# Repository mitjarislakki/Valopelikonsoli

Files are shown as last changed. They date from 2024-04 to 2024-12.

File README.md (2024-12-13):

# Valopelikonsoli

pic of console

Valopelikonsoli ("Light game console") is an Arduino-based simple 2-player game console created as part of an electrical workshop project course at Aalto University in Spring 2024. It uses a keypad matrix to handle the switches with fewer pins.

Created with PlatformIO + Arduino lib using C++ and the following libraries (defined in [platformio.ini](./platformio.ini)):
- duinowitchery/hd44780@^1.3.2
- fastled/FastLED@^3.6.0

Implemented games:
- Whack-a-mole, where the aim is to be the first to hit the yellow light which lights up on both sides, while avoiding red lights.
- Memory game, where a random pattern keeps increasing by one every time the player gets it correct (asynchronous for players)
- Speed game, where lights appear in random places and the player must press as many as possible in the time limit (asynchronous for players)

## BOM / parts

| Part | Quantity | Note |
| --- | --- | --- |
| PCF8574 I2C backpack/HD44780 16x2 LCD module |	2	| I2C-based screens, 1 per player |
| 10 K resistor |	4	| Pulldown for the columns of the matrix |
| 4.8 K resistor |	2 |	I2C pull-up |
| DT44L12-W arcade buttons with switches	| 15 | 7 buttons per player + reset |
| NeoPixel ARGB LED |	14 |	Addressable LEDs to place inside buttons |
| IN4148 Diodi |	14	| Blocking reversed current in matrix |
| Arduino UNO R3 | 1	| Microcontroller, Mini also has enough pins |
| 9V -battery	| 1	| Power source for Arduino/LEDs |
| 9V battery holder with DC5521 -jack |	1 |	Power switch and connector to Arduino |
| Dupont-connector cables	| A lot |	Male-male & male-female |

## Implementation

### Displays

displays

The original idea was to use OLED displays for both color and higher resolution, but the workshop could not find any displays of suitable size and the basic 64x128 monochrome SSD1306 would require a 64*128=8192-bit (1024 bytes) buffer, so two displays would fill the Arduino UNO's 2048 byte SRAM. In the implementation, we therefore ended up using regular 2x16 seven-segment LCD displays, but with I2C backpacks instead of SPI to save on the Arduino's pin count. The workshop's I2C-LCD displays (including the 1602 LCD module) utilize Hitachi's HD44780 LCD controller with Texas Instruments' PCF8574 I2C I/O expansion chip. We found an easy-to-use HD44780.h library for this combination, which has a separate hd44780_I2Cexp subclass for controlling the I2C backpack.

To control two I2C displays, you must ensure that the displays have different I2C addresses. In the case of LCD modules, the address change is done by soldering two marked areas on the circuit board together. In the actual connection, the SDA/SCL connections of the displays are connected in parallel, but I2C pull-up resistors are needed before the corresponding connections on the Arduino.

We attached the screens to the console frame by drilling two holes in the console on each player's side. This allowed us to attach the screens with a string.

### Frame

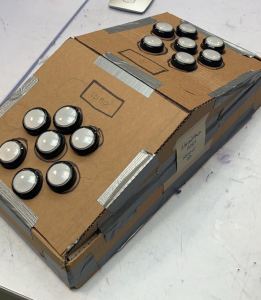
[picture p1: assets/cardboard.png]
cardboard


Cardboard prototype

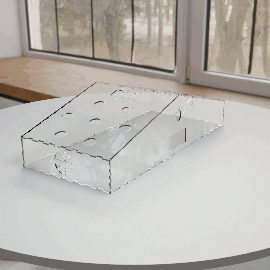
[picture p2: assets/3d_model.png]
3d model


3D model in Blender with reduced size compared to prototype. Was laser cut according to the modeled object ([SVG file](assets/laser_cutting.svg))

### Buttons

[A holder suitable for DT44L12-W buttons that can accommodate four connections for an ARGB LED](assets/LED_holder_2.stl) (STL file)

The workshop didn't have ready-made Arcade-style pushbuttons with ARGB LEDs and ready-made solutions were expensive, so we implemented them ourselves with DT44L12-W buttons. For the buttons, a four-pin holder was created for the LEDs, two of which (DIN and DOUT) work with the button connections and the power is provided by new wires coming out of the buttons.

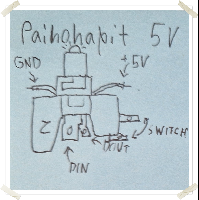
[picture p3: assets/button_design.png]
button design


The LED was attached to the printed holder so that the connections did not touch each other and the outermost connections (DIN, DOUT) were connected to the existing connections of the buttons. The new connections required two gaps between the switch and the holder, which were ground with a small file on each switch holder. The new connections were soldered with wires, which were still insulated in the printed holder with electrical tape, in order to avoid mixing of the signals of the connections.

button assembly

The functionality of the button LEDs was verified by testing both a single button and a series connection, where the DOUT of one button continues to the DIN connector of the other button. It is important to note in the project that not all ARGB LEDs are of the same type, which was reflected in the fact that some of the LEDs initialized blue when started, while some remained off. At the same time, the series connection of the LEDs did not work with every order of buttons, but a working series had to be manually tested. No reasonable explanation has been found for this, as the order did not depend on the types of LEDs. In the broken series, the LEDs started flashing randomly and did not follow the value given in the code.

### Key matrix

The Arduino UNO has 14 digital I/O connections, which would not be enough for this project if each component was connected separately, which is why the LEDs have been connected in series. Despite this, the Arduino still would not have enough connections if each switch were separate. For this reason, the console utilizes a keypad matrix adapted from computer keyboards, where several switches are connected to rows and columns and the controller repeatedly scans one row at a time if a button in the column is active (state HIGH).

For the matrix, the wiring had to be created according to the wiring diagram with connectors, where 3-4 switches were in a row in parallel and 2-4 in a column in parallel. In the case of columns, diodes were used in series with the switch to avoid ghost presses, as otherwise current could flow to other rows when several switches were pressed.

### Wiring

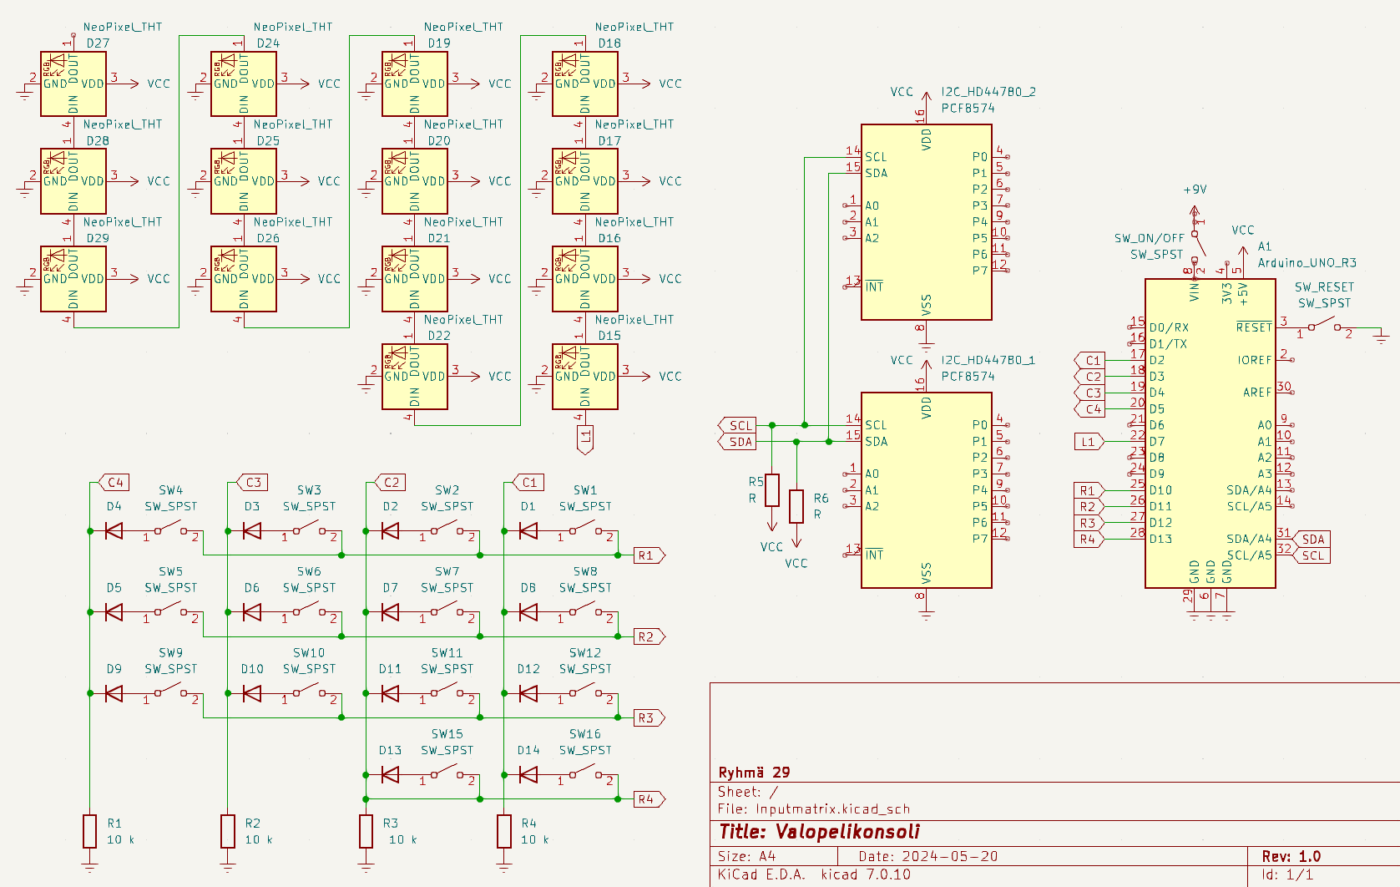
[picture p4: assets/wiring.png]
wiring plan


(The PCF8574 components are part of the I2C/LCD modules, meaning that connections other than VCC/VSS/SCL/SDA are part of the module and not marked in the diagram.)

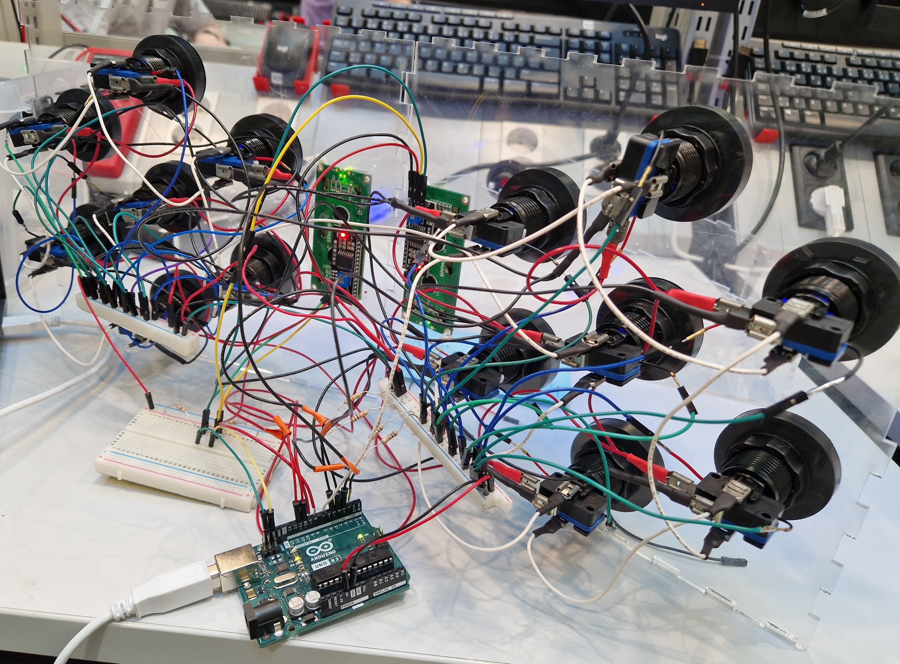
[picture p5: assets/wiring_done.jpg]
wiring done


### Program

Found in [src/menu.cpp](src/menu.cpp) and [src/patterns.h](src/patterns.h)

## Conclusions from the project

The project was quite successful overall and all participants learned a lot. One clear area for improvement would be wiring, as the use of breadboards and Dupont wires led to situations where a single wire would come loose from inside the console, causing hard-to-trace operational problems that took time to resolve.
On the other hand, in terms of sustainability, using detachable wires meant easy disassembly and possibility of reuse.

Otherwise, the console is a fairly complete package and any further development would likely involve creating new games or converting the code to a more readable format,
as it currently contains somewhat confusing structures. Many functions should also be separated into their own functions and class structures, and refactored to utilize shared structures.
The existing format is a remnant of both experimenting with the hardware and people working independently without much coordination.

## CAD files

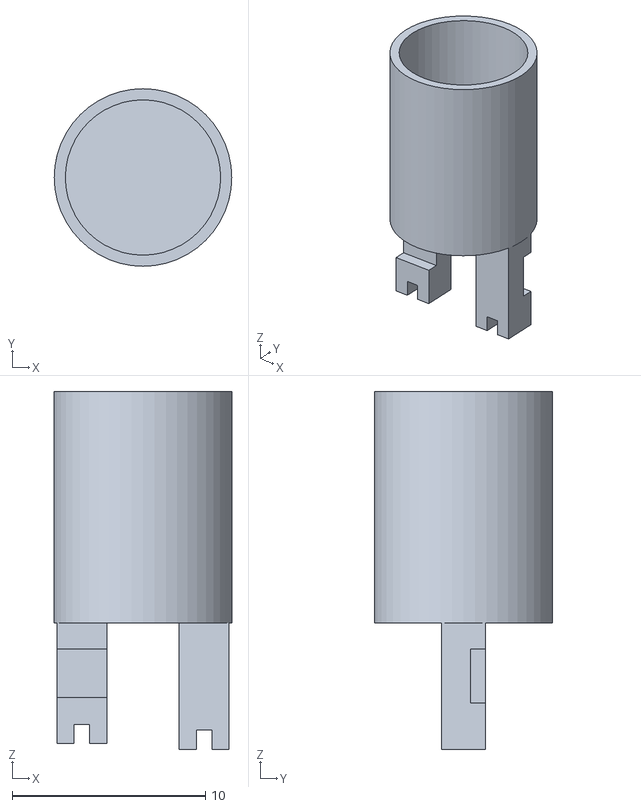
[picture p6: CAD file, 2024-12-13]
assets/LED_holder_2.stl
9.18 x 9.18 x 18.5

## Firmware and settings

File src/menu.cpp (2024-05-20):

#include <Arduino.h>
#include <FastLED.h>
#include <stdlib.h>
#include <Wire.h>
#include <hd44780.h>                       // main hd44780 header
#include <hd44780ioClass/hd44780_I2Cexp.h> // i2c expander i/o class header

#include "patterns.h"

// Print debug information to serial
constexpr bool debug = true;

#define MOLE_TIMER 30 // Length of whack-a-mole game in seconds
#define SPEED_TIMER 30 // Length of speed game in seconds

//Screen settings:
hd44780_I2Cexp p1LCD;
hd44780_I2Cexp p2LCD;
const int LCD_COLS = 16;
const int LCD_ROWS = 2;

#define MOLE_MIN (long)500
#define MOLE_MAX (long)2000

//LED settings:
#define LED_PIN 7
#define LED_TYPE NEOPIXEL
#define COLOR_ORDER GRB
#define NUM_LEDS 16
CRGB leds[NUM_LEDS];

/*
Input Matrix

kytke diodit niin että virta menee row → col:
row → napit → IN4148 diodit → col + 10k pulldown
*/

// Matrix row/col pins
const int row[] = {8,9,10,11};
const int col[] = {2,3,4,5};
const int size = 4;
int keys[size*size];
int lastKeys[size*size];
constexpr long debounceDelay = 200;
unsigned long lastDebounce[size*size] = {0};


// Players
Player p1;
Player p2;

//Menu
int mode = 0;
String modes[] = {"Memory Game", "Whac-a-mole", "Speed Game"};
int selection = -1;

unsigned long startTime = 0;

//paskapeli
int currentP1 = -1;
int lastP1 = -1;
int currentP2 = -1;
int lastP2 = -1;

//moles
int currentMoles[] = {0,0,0,0,0,0,0};
unsigned long nextMole = 0;

// Player LED numbers
const int p1LED[] = {0,1,2,3,4,5,6};
const int p2LED[] = {7,12,11,10,9,8,13};

// Player matrix pins
const int p1Keys[] = {0,1,2,3,4,5,6};
const int p2Keys[] = {7,13,12,10,9,8,14};

// patterns
#define PATTERN_LENGTH 100
#define PATTERN_INTERVAL 500
int pattern[PATTERN_LENGTH];

// put function declarations here:

void updateKeys(unsigned long);
void showScores();
void paskapeli();
void clearLeds();
bool onKeyDown(int key);
void updateScreens(String disp);
void menu();
void showPatterns(unsigned long);
void initializePlayer(Player*);
void nextPattern(Player*, const int*);
void processInputs(Player*, const int*);
void timedGame(int game, int timer, unsigned long currentTime);
void moles(unsigned long currentTime);
void failPlayer(Player*, const int*);
void endGame();


void initializePlayer(Player* player){
    player->inPattern = true,
    player->patternStart = true,
    player->patternIndex = 0,
    player->patternMax = 1,
    player->prevTime = 0,
    player->score = 0;
}

void setup() { 
    initializePlayer(&p1);
    initializePlayer(&p2);

    randomSeed(analogRead(0)); //randomise seed to avoid every time being the same after reset
    
    // Set up the pattern
    for (int i = 0; i < PATTERN_LENGTH; i++){
        pattern[i] = random(0, 7);
    }

    Serial.begin(9600); //enable serial for debugging
    //pin setup for button matrix:
    for(int i=0; i < size; i++){
        pinMode(row[i], OUTPUT);
        pinMode(col[i], INPUT);
    }
    //led strip initialization
    FastLED.addLeds<LED_TYPE, LED_PIN>(leds, NUM_LEDS).setCorrection(TypicalLEDStrip);

    //clear leds
    clearLeds();

    //LCD initialization
    int status1;
    int status2;
        
    status2 = p2LCD.begin(LCD_COLS, LCD_ROWS);
    status1 = p1LCD.begin(LCD_COLS, LCD_ROWS);
    if(status1) hd44780::fatalError(status1);
    if(status2) hd44780::fatalError(status2);

    // initalization was successful, the backlight should be on now
    // Print a message to the LCD
    p1LCD.print("Valopeli, P1");
    p2LCD.print("Valopeli, P2");
    delay(2000);
    updateScreens("Select Game:");
    delay(1100);
    updateScreens(""); // Set to default
}

void loop() {
    // Get current running time
    unsigned long currentTime = millis();

    // update keypress map
    updateKeys(currentTime);

    // Print keys
    if(debug){
        for(int i=0; i < size; i++){
            for(int j = 0; j < size; j++){
                Serial.print(keys[size*i+j]);
            }
                Serial.print(" ");
        }
        Serial.println();
    }

    //mode 0 = menu, 1 = memory game etc.
    if(mode == 0){
        menu();
    }
    else if(mode == 1){
        // Memory game
        // Update pattern
        showPatterns(currentTime);

        if(!p1.failed) processInputs(&p1, p1Keys);
        if(!p2.failed) processInputs(&p2, p2Keys);
        if(p1.failed && p2.failed) endGame();
    }
    else if(mode == 2){
        //Whac-a-mole
        timedGame(2, MOLE_TIMER*1000, currentTime);
    }

    else{
        //Speed game
        timedGame(3, SPEED_TIMER*1000, currentTime);
    }
    delay(10);
}

// function definitions:

//reads the state of the matrix and puts it into array keys,
// keys[i] represents whether or not i:th key is pressed
void updateKeys(unsigned long currentTime){
    for(int i=0; i < size; i++){
        for(int k=0; k < size; k++){
        digitalWrite(row[k], LOW);
        }

        digitalWrite(row[i], HIGH);
        for(int j = 0; j < size; j++){
            int state = digitalRead(col[j]);
            int btnIndex = i*size + j;
            lastKeys[btnIndex] = keys[btnIndex];
            if(state != lastKeys[btnIndex] && (currentTime - lastDebounce[btnIndex]) > debounceDelay){
                lastDebounce[btnIndex] = currentTime;
                keys[btnIndex] = state;
            }
        }
        digitalWrite(row[i], LOW);
    }
}

//updates the screens to show the points of player 1 and 2
void updateScreens(String disp){
  if(disp == ""){
    p1LCD.clear();
    p2LCD.clear();
    p1LCD.print("Player 1: " + String(p1.score));
    p2LCD.print("Player 2: " + String(p2.score));
  }
  else{
    p1LCD.clear();
    p2LCD.clear();
    p1LCD.print(disp);
    p2LCD.print(disp);
  }
}

// Returns random free pin between min and max, that's not current
int randomPin(int current, int min, int max){
    int i = random(min, max);
    while(i == current) i = random(min, max);
    return i;
}

//show player scores on bottom row of both LCDs
void showScores(){
    p1LCD.setCursor(0,1);
    p1LCD.print(String(p1.score) + " vs " + String(p2.score));
    p2LCD.setCursor(0,1);
    p2LCD.print(String(p1.score) + " vs " + String(p2.score));
}

void showPatterns(unsigned long currentTime){
    // Check if in pattern phase and interval has passed
    bool p1Next = ((unsigned long)(currentTime - p1.prevTime) >= PATTERN_INTERVAL);
    bool p2Next = ((unsigned long)(currentTime - p2.prevTime) >= PATTERN_INTERVAL);

    // Check p1
    if(p1.inPattern && p1Next){
        nextPattern(&p1, p1LED);
        p1.prevTime = currentTime; // Time check
        FastLED.show();
    }

    // Check p2
    if(p2.inPattern && p2Next){
        nextPattern(&p2, p2LED);
        p2.prevTime = currentTime; // Time check
        FastLED.show();
    }
}

// Show the next LEDs in the pattern
void nextPattern(Player* player, const int* pins){
    int i = player->patternIndex;
    if(debug) Serial.print(pattern[i]);
    if(player->patternStart){
        player->patternStart = false;
        leds[pins[pattern[i]]] = CRGB::Red;
    }
    else{
        // Set the previous LED in the pattern to off
        leds[pins[pattern[i]]] = CRGB::Black;
        player->patternIndex++;
        // Check if at the max index
        if(player->patternIndex == player->patternMax){
            player->inPattern = false; // End of pattern
            player->patternStart = true; // Start flag for next iteration
            player->patternIndex = 0;
            if(debug) Serial.println();
        }    
        else leds[pins[pattern[player->patternIndex]]] = CRGB::Red; // Next in pattern
    }
    FastLED.show();
}

// Check that the player input is the pattern
void processInputs(Player* player, const int* playerKeys){
    // Check that player in pattern phase and expected button is pressed
    if(!player->inPattern){
        int correctKey = playerKeys[pattern[player->expected]];
        // Check that no other key than the correct one is pressed
        bool failed = false;
        for(int i = 0; i < 7; i++){
            int key = playerKeys[i]; 
            if(keys[key] == HIGH && !lastKeys[key] && key != correctKey){
                failed = true;
                break;
            }
        }
        if(failed) failPlayer(player, playerKeys); // Fail the player if failure detected
        else if(keys[correctKey] == HIGH){
            player->expected++; // Increment expected button
            if(player->expected == player->patternMax){
                player->score++; // Increment player's score
                player->expected = 0; // Expect the first in pattern
                player->patternMax++; // Increment the pattern by one
                // Avoid pattern overflow (max is PATTERN_LENGTH)
                if(player->patternMax == PATTERN_LENGTH) player->patternMax = 1;
                player->inPattern = true; // Show the next pattern
                updateScreens(""); // Update screens
            }
        }

    }
}

//check for new keypress
bool onKeyDown(int key){
    if(keys[key] && !lastKeys[key]){
        return true;
    }
    else return false;
}

//handle the menu
void menu(){
    if(selection == -1){
            selection = 0;
            updateScreens(modes[0]);
            leds[p1LED[1]] = CRGB(255,255,255);
            leds[p1LED[4]] = CRGB(255,255,255);
            leds[p1LED[6]] = CRGB(255,0,0);
            FastLED.show();
        }
        if (onKeyDown(p1Keys[1])){
            selection = selection-1;
            if(selection<0){selection = 0;}
            updateScreens(modes[selection]);
        }
        else if (onKeyDown(p1Keys[4])) {
           selection = selection+1;
            if(selection>2){selection = 2;}
            updateScreens(modes[selection]); 
        }
        else if (onKeyDown(p1Keys[6])){
            clearLeds();
            mode = selection + 1;
            updateScreens("3");
            delay(700);
            updateScreens("2");
            delay(700);
            updateScreens("1");
            delay(700);
            updateScreens("");
        }
}

//turn off all leds
void clearLeds(){
    for(int i = 0; i < NUM_LEDS; i++){
        leds[i] = CRGB::Black;
    }
    FastLED.show();
}

//handle the logic for the speed game
void paskapeli(){
    if(currentP1 == -1){
        currentP1 = randomPin(lastP1,0,7);
        lastP1 = currentP1;
    }
  //do the same for player 2
    if(currentP2 == -1){
        currentP2 = randomPin(lastP2,0,7);
        lastP2 = currentP2;
    }
  leds[p1LED[currentP1]] = CRGB(255,255,255); //turn on the current leds for player 1 and 2
  leds[p2LED[currentP2]] = CRGB(255,255,255);
  FastLED.show();

  //check if player 1 is pressing the correct button, give point and set to randomise new led
  if(keys[p1Keys[currentP1]] == HIGH){
    //check if player 1 is also pressing an incorrect key, in that case, don't give points
    int pass1 = 1;
    for(int i = 1; i<7; i++){
      if(i!=currentP1 && keys[p1Keys[i]] == HIGH){
        pass1 = 0;
        break;
      }
    }
    if(pass1 == 1){
      leds[p1LED[currentP1]] = CRGB::Black;
      currentP1 = -1;
      p1.score++;
      updateScreens("");
    }
  }
  if(keys[p2Keys[currentP2]] == HIGH){
    //check if player 2 is also pressing an incorrect key, in that case, don't give points
    int pass2 = 1;
    for(int i = 1; i<7; i++){
      if(i!=currentP2 && keys[p2Keys[i]] == HIGH){
        pass2 = 0;
        break;
      }
    }
    if(pass2 == 1){
      leds[p2LED[currentP2]] = CRGB::Black;
      currentP2 = -1;
      p2.score++;
      updateScreens("");
    }
  }
}

//higher level handler for the timed games, runs game for set time, then shows results
void timedGame(int game, int timer, unsigned long currentTime){
    //game = game number
    //timer = time before end in millis
    if(startTime == 0){startTime = millis();}
    if(currentTime < startTime + timer){ //game still running
        if(game == 2) moles(currentTime);
        else if(game == 3) paskapeli();
        }
    else endGame();
}



//handle the logic for the mole game
void moles(unsigned long currentTime){
    //mole array: 0 = empty, 1 = mole, 2 = snake
    //randomize time for next mole
    if(nextMole == 0){
        nextMole = currentTime + random(MOLE_MIN, MOLE_MAX); //change mole timing here
    }
    //add mole
    if(currentTime >= nextMole){
        nextMole = 0;
        //remove old snakes
        for(int i=0; i <7; i++){
            if (currentMoles[i] == 2) currentMoles[i] = 0;
        }
        int moleType = (int)random(1,8);
        if(moleType > 6) moleType = 2;
        else moleType = 1;
        int newMole[] = {(int)random(0,7), moleType};
        currentMoles[newMole[0]] = newMole[1];
    }
    //update LEDs
    for(int i = 0; i < 7; i++){
        //player 1
        if (currentMoles[i] == 0){
            leds[p1LED[i]] = CRGB::Black;
            leds[p2LED[i]] = CRGB::Black;
        }
        else if (currentMoles[i] == 1){
            leds[p1LED[i]] = CRGB(175,255,0); //mole color
            leds[p2LED[i]] = CRGB(175,255,0); 
        }
        else {
            leds[p1LED[i]] = CRGB(0,255,0); //snake color
            leds[p2LED[i]] = CRGB(0,255,0);
        }
        FastLED.show();
    }
    //check if mole is pressed, give points
    for(int i = 0; i < 7; i++){
        //player 1
        if(onKeyDown(p1Keys[i])){
            if (currentMoles[i] == 1) p1.score++;
            else if(currentMoles[i] == 2) p1.score--;
            //player 1 and 2
            if (onKeyDown(p2Keys[i])){
                if (currentMoles[i] == 1) p2.score++;
                else if(currentMoles[i] == 2) p2.score--;
            }
            currentMoles[i] = 0;
            updateScreens("");
        }
        //player 2 only
        else if(onKeyDown(p2Keys[i])){
            if (currentMoles[i] == 1) p2.score++;
            else if(currentMoles[i] == 2) p2.score--;
            currentMoles[i] = 0;
            updateScreens("");
        }
    }
    
}

void failPlayer(Player* player, const int* playerKeys){
    player->failed = true;
    for(int i = 0; i < 7; i++){
        leds[playerKeys[i]] = CRGB::Green;
    }
    FastLED.show();
}

void endGame(){
    if(p1.score > p2.score){ //game ended, p1 won
        updateScreens("Player 1 won!");
        showScores();
        for(int i=0; i<7;i++){
            leds[p1LED[i]] = CRGB(255,0,0);
            leds[p2LED[i]] = CRGB(0,255,0);
        }
        FastLED.show();
        delay(60000);
    }
    else if(p2.score > p1.score){
        updateScreens("Player 2 won!");
        showScores();
        for(int i=0; i<7;i++){
            leds[p2LED[i]] = CRGB(255,0,0);
            leds[p1LED[i]] = CRGB(0,255,0);
        }
        FastLED.show();
        delay(60000);}
    else{
        updateScreens("Tie!");
        showScores();
        for(int i=0; i<7;i++){
            leds[p1LED[i]] = CRGB(175,255,0);
            leds[p2LED[i]] = CRGB(175,255,0);
        }
        FastLED.show();
        delay(60000);}
}

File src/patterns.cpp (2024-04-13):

#include <Arduino.h>
#include <FastLED.h>
#include <stdlib.h>
#include <Wire.h>
#include <hd44780.h>                       // main hd44780 header
#include <hd44780ioClass/hd44780_I2Cexp.h> // i2c expander i/o class header

//Näyttöjen asetukset:
hd44780_I2Cexp lcd1;
hd44780_I2Cexp lcd2;
const int LCD_COLS = 16;
const int LCD_ROWS = 2;

//Ledien asetukset:
#define LED_PIN 7
#define LED_TYPE NEOPIXEL
#define COLOR_ORDER GRB
#define NUM_LEDS 31
CRGB leds[NUM_LEDS];

/*
Input Matrix

kytke diodit niin että virta menee row → col:
row → napit → IN4148 diodit → col + 10k pulldown
*/

// Matrix row/col pins
const int row[] = {8,9,10,11};
const int col[] = {2,3,4,5};
const int size = 4;
int keys[size*size];

// Number of LEDs
const int numLeds = 31;

// Player LED numbers
const int LedP1[] = {0,1,2,3,4,5,6};
const int LedP2[] = {7,8,9,10,11,12,13};

// Player matrix pins
const int KeysP1[] = {15,14,13,12,11,10,9};
const int KeysP2[] = {7,6,5,4,3,2,1};

// Player scores
int scoreP1 = 0;
int scoreP2 = 0;

// patterns
#define PATTERN_LENGTH 100
int pattern[PATTERN_LENGTH];

#define PATTERN_INTERVAL 500

bool p1Pattern;
bool p2Pattern;
bool p1PStart = true;
bool p2PStart = true;

// player pattern indexes
int indexP1P = 0;
int indexP2P = 0;
unsigned long prevTimeP1P = 0;
unsigned long prevTimeP2P = 0;

// player pattern variables

int p1Cur = 0;
int p2Cur = 0;
int p1Max = 1;
int p2Max = 1;


// put function declarations here:

void updateKeys();
void updateScreens();
void showPatterns(unsigned long);


void setup() { 
    p1Pattern = true;
    p2Pattern = true;

    randomSeed(analogRead(0)); //randomise seed to avoid every time being the same after reset
    
    // Set up the pattern
    for (int i = 0; i < PATTERN_LENGTH; i++){
        pattern[i] = random(0, 6);
    }

    Serial.begin(9600); //enable serial for debugging
    //pin setup for button matrix:
    for(int i=0; i < size; i++){
        pinMode(row[i], OUTPUT);
        pinMode(col[i], INPUT);
    }
    //led strip initialization
    FastLED.addLeds<LED_TYPE, LED_PIN>(leds, NUM_LEDS).setCorrection(TypicalLEDStrip);

    //clear leds
    for(int i = 0; i < NUM_LEDS; i++){
        leds[i] = CRGB::Black;
    }
    FastLED.show();

    //LCD initialization
    int status1;
    int status2;
        
    status1 = lcd1.begin(LCD_COLS, LCD_ROWS);
    status2 = lcd2.begin(LCD_COLS, LCD_ROWS);
    if(status1) hd44780::fatalError(status1);
    if(status2) hd44780::fatalError(status2);

    // initalization was successful, the backlight should be on now
    // Print a message to the LCD
    lcd1.print("Valopeli, P1");
    lcd2.print("Valopeli, P2");
    delay(2000);
    lcd1.clear(); lcd1.print("3");
    lcd2.clear(); lcd2.print("3");
    delay(700);
    lcd1.clear(); lcd1.print("2");
    lcd2.clear(); lcd2.print("2");
    delay(700);
    lcd1.clear(); lcd1.print("1");
    lcd2.clear(); lcd2.print("1");
    delay(700);
    updateScreens();
}

void loop() {
    // Get current running time
    unsigned long currentTime = millis();

    // Update pattern
    showPatterns(currentTime);
    // update keypress map
    updateKeys();

    if(!p1Pattern && keys[KeysP1[pattern[p1Cur]]] == HIGH){
        p1Cur++;
        if(p1Cur == p1Max){
            scoreP1++;
            p1Cur = 0;
            p1Max++;
            if(p1Max == PATTERN_LENGTH) p1Max = 1;
            p1Pattern = true;
            updateScreens();
        }
    }
    if(!p2Pattern && keys[KeysP2[pattern[p2Cur]]] == HIGH){
        p2Cur++;
        if(p2Cur == p2Max){
            scoreP2++;
            p2Cur = 0;
            p2Max++;
            if(p2Max == PATTERN_LENGTH) p2Max = 1;
            p2Pattern = true;
            updateScreens();
        }
    }
    delay(10);
}

// function definitions:

//reads the state of the matrix and puts it into array keys,
// keys[i] represents whether or not i:th key is pressed
void updateKeys(){
    for(int i=0; i < size; i++){
        for(int k=0; k < size; k++){
        digitalWrite(row[k], LOW);
        }

        digitalWrite(row[i], HIGH);
        for(int j = 0; j < size; j++){
            int state = digitalRead(col[j]);
            if(state == HIGH){
                keys[i*size+j] = HIGH;
            }
            else{
                keys[i*size+j] = LOW;
            }
        }
        digitalWrite(row[i], LOW);
    }

  
}

//updates the screens to show the points of player 1 and 2
void updateScreens(){
  lcd1.clear();
  lcd2.clear();
  lcd1.print("Player 1: " + String(scoreP1));
  lcd2.print("Player 2: " + String(scoreP2));
}

// Returns random free pin between min and max, that's not current
int randomPin(int current, int min, int max){
    int i = random(min, max);
    while(i == current) i = random(min, max);
    return i;
}

// TODO - ratkaise ensimmäisen indeksin ongelma :D
void showPatterns(unsigned long currentTime){
    // Check if in pattern phase and interval has passed
    bool p1Next = ((unsigned long)(currentTime - prevTimeP1P) >= PATTERN_INTERVAL);
    bool p2Next = ((unsigned long)(currentTime - prevTimeP2P) >= PATTERN_INTERVAL);

    // Check p1
    if(p1Pattern && p1Next){
        Serial.print(pattern[indexP1P]);
        if(p1PStart){
            p1PStart = false;
            leds[LedP1[pattern[indexP1P]]] = CRGB::Red;
        }
        else{
            // Set the previous LED in the pattern to off
            leds[LedP1[pattern[indexP1P]]] = CRGB::Black;
            indexP1P++;
            // Check if at the max index
            if(indexP1P == p1Max){
                p1Pattern = false; // End of pattern
                p1PStart = true; // Start flag for next iteration
                indexP1P = 0;
                Serial.println();
            }    
            else leds[LedP1[pattern[indexP1P]]] = CRGB::Red; // Next in pattern
        }
        prevTimeP1P = currentTime; // Time check
        FastLED.show();
    }

    if(p2Pattern && p2Next){
        Serial.print(pattern[indexP2P]);
        if(p2PStart){
            p2PStart = false;
            leds[LedP2[pattern[indexP2P]]] = CRGB::Red;
        }
        else{
            leds[LedP2[pattern[indexP2P++]]] = CRGB::Black;
            if(indexP2P == p2Max){
                p2Pattern = false;
                p2PStart = true;
                indexP2P = 0;
                Serial.println();
            }
            else leds[LedP2[pattern[indexP2P]]] = CRGB::Red;
        }
        prevTimeP2P = currentTime;
        FastLED.show();
    }
}

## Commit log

2024-02-07 Add simple fading button concept
2024-03-07 Added prototype1
2024-03-11 Added comments and blocked scoring if incorrect button is pressed
2024-03-21 add single thread memory game
2024-04-13 add comments, change timer to long from int
2024-04-13 add build environment - refactor patterns to timer-based concurrent execution with player structs
2024-05-02 change button pins & LCDs to match wiring
2024-05-09 update LEDs/Pins, add button press print debug
2024-05-13 LED test
2024-05-20 add debounce, timer variables, debugging
2024-12-13 create README with image + STL/SVG file assets
    [LED_holder_2.stl]
